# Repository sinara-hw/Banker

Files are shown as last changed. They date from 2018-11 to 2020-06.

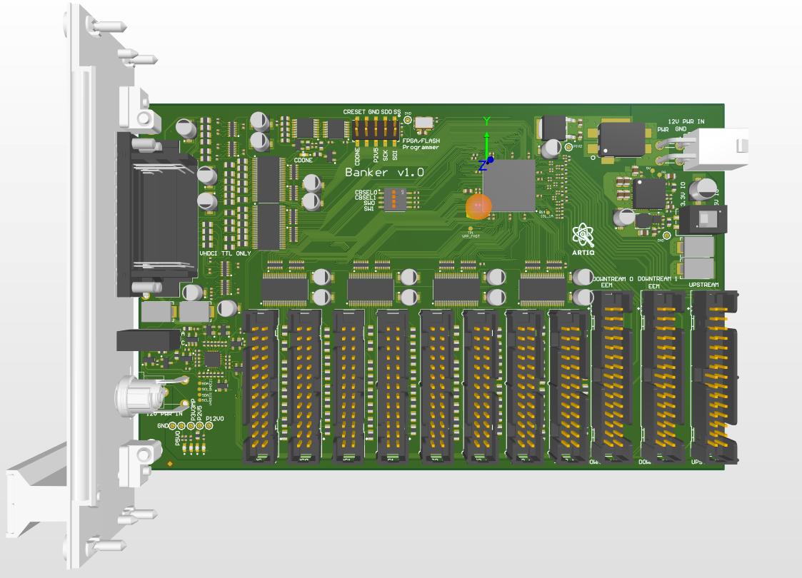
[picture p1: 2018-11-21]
Banker_Top.PNG

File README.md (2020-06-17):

# Banker

EEM with 128 TTL DIOs (64 via local BNC, 64x via VHDCI)

## Design Files

Design files (schematics, PCB layouts, BOMs) can be found at [Banker/Releases](https://github.com/sinara-hw/Banker/releases).

## Wiki

More information can be found on the [wiki](https://github.com/sinara-hw/Banker/wiki).

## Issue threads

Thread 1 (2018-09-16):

schematic review

gkasprow, 2018-09-16:
I did initial [schematics](https://github.com/sinara-hw/Banker/releases/tag/v1.0rc) and component placement.
@jordens @hartytp @dtcallcock @sbourdeauducq please have a look at it.

gkasprow, 2018-09-16:
I did power supply in such way on purpose. When sb plugs it to LVDS port, 5V would be shorted to GND and PTC fuse will get activated. So nothing would be damaged
I used Molex connector (ATX type) on the PCB rear side. I think in next revision of VHDCI carrier and Kasli we should also use them.  It is much more reliable than DC jacks. In case of DC jacks its possible to not lock it. With Molex one it is really hard.
FPGA FLASH can programmed with 10$ programmer, via I2C or via FPGA itself. I added a circuit that allows FPGA to reboot itself.
Additional circuit makes sure that level translators / buffers get activated some time after FPGA configures and reset pulse is released. All IOs have 10k pulldowns.
I2C is protected with TVS
DIP switch is connected to CSBSEL lines that let us choose which binary to boot or can be used as general purpose config input. It is also connected via 10k to FLASH lines that after configuration can be used as GPIO
Front panel LEDs indicate power, Config DONE, I2C FLASH update mode and user defined signal
I2C switch has its own reset circuit
Translators have 22R resistors towards FPGA. It is to limit the current in case of logic level contention.
Downstream ports have 300mA PTCs.
I used 6A 5V DC/DC because it is low cost. And when sb drives 128 channels with 25mA it gives already 3.2A

Shall I add 50Ohm resistors at the drivers output? They take some place and I'm not sure if we need impedance matching.

jordens, 2018-09-17:
Nice!

* Make sure the right pins end up on the GBINs. I'd go for VHDCI0_0, VHDCI1_0, IDC0_0_0, IDC1_0_0, IDC2_0_0, and the 25 MHz clock. On the LVDS bank it's ok.
* I think all the LVDS lines on the three EEM need external termination. Both parallel for input and series for output. Maybe just scrap one downstream EEM if it gets too much.
* The I2C switch reset should be controllable by the FPGA. I see no other way to get out of a hung bus.
* I2C addresses look ok.
* Could we have an easy option to make the TTL level 3.3V (instead of 5V)? Just a couple more resistors/bridges around R367/R368 so that a solder blob will make it 3.3V.
* The drivers have about 10 Ohm output impedance. I'd keep the 30-40 in series. But I see no real need for input parallel termination.
* I don't think the path after IC3 to RSTn to the FPGA is necessary. An internal counter-based delay after configuration should be sufficient. Instead I would drive DRV_OENn from the FPGA (IOL_9B)
* The CFG_RELOAD from the FPGA to CRESET is probably not necessary. There is the SB_WARMBOOT primitive that seems to be able to do that internally. I'd check it though.

* I would put the EEM connectors on the bottom (like Kasli and the others)
* Put the upstream EEM to the right and the downstream ones to the left: "down0, down1, up" from left to right.
* Make sure the bottom (left) VHDCI is VHDCI0 and the top/right VHDCI1.
* Spread out the power and the VHDCI connector as much ass possible on the panel. Without colliding with the handle.
* I'd put the JTAG headers closer to the FPGA.

gkasprow, 2018-09-17:
@jordens ACK All
To simplify routing of power plane I will use 2.5V for all logics.
And will get rid of one downlink EEM. Otherwise I would have to use 6 layers for BGA fanout. I'm not sure if it is worth. It would increase the PCB cost by 30%.
Variable supply for TTL would be generated at the main buck converter, so all IOs would be affected. Is that OK?

jordens, 2018-09-17:
Yes. That's all fine. The alternative would be to have two (3.3/5) domains and split the 128 channels into two power groups. But I don't think that's worth it. People can just get another Banker.

gkasprow, 2018-09-17:
We can indicate 3.3 / 5V operation with front panel LED.

gkasprow, 2018-09-17:
I plan to add  series 33R on each DIO + 50Ohm at the other side of the cable.
In this way when driven from very low impedance, the transmission line would be still source-terminated.
When shorted, the driver will dissipate 5V^2/100R, so two 0.125W resistors would be sufficient.

jordens, 2018-09-17:
Or even 39R.

gkasprow, 2018-09-17:
Yes, I placed 39 Ohms.

gkasprow, 2018-09-19:
@jordens to my surprise, I managed to fanout all signals using mainly2 layers. Just a few signals were routed on third layer reserved for power distribution.
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
Altium pin swapping feature was great help here. Please have a look:
[Banker.PDF](https://github.com/sinara-hw/Banker/files/2397721/Banker.PDF)

dhslichter, 2018-09-19:
How much power dissipation are you going to get if you have 96 channels and each one is driving a 50-ohm terminated load?  The drivers on the schematic will source or sink 32 mA with 5V supply, which means that the logic high will only be 1.6 V across a 50 ohm termination (itself a potential problem).  The dissipation on the board would then be ~100 mW per terminated channel for a logic high, or worst case ~ 10 W.  I think you can't really run a 50 ohm termination at the far end with these lines, would be my point...might have to just plan on the series termination being enough.  You might place a high-current driver on the breakout if you want, for certain channels?

Also, EMI/crosstalk is going to be not great with long cables, and larger currents will make inductive coupling worse....

jordens, 2018-09-19:
I don't think delivering power into 50 ohms on 128 or even only 32 channels is a design goal. I'd just make sure that the power supply trips in a well defined way before anything blows up.

gkasprow, 2018-09-19:
I will add LM75 that will shut down the PSU after exceeding 80 degrees...

dhslichter, 2018-09-19:
All fine.  I just saw comments above talking about terminating loads with 50 ohms at the far end, and I wanted to point out that this is probably not going to work here.  The whole purpose of Banker is to be somewhat time-insensitive digital I/O, though, so I would imagine that they can be made high-impedance inputs.  Series termination at the source will be sufficient for most applications anyway.

jordens, 2018-09-20:
@gkasprow A couple more things after looking again at the [Lattice LVDS AN](https://www.latticesemi.com/-/media/LatticeSemi/Documents/ApplicationNotes/UZ/UsingDifferentialIOLVDSSubLVDSiniCE40Devices.ashx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):

* The positive LVDS (EEMx_y_P) is generally the B pin (IOL_zB), not the A.
* DBIN7 is special and should be EEM0_0_PN as currently but with polarity swapped.
* I would put EEM0_4_P/N on GBIN6 for another SPI bus on EEM0_4-7.
* LVDS outputs need series resistors (mentioned above) as well. We want some outputs. I'd go for EEM0_{2,6}, EEM1_{0,1,3,4,5,7}, EEM2_{0,1,3,4,5,7}. But if there is space, I'd put those series resistor everywhere.

gkasprow, 2018-09-20:
It looks like ICE 40 does not implement LVDS transmitters at all. Only receivers.
I though that these resistive networks are needed for sub-LVDS outputs only.
The image:
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
 states that IOL_1A is positive and IOL_1B is negative

they also say:

 _Connect the positive or true polarity side of the differential pair to the DPxxA input and the negative or complementary side of the pair to the DPxxB input._
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
jordens, 2018-09-25:
* [Banker EDGE2DSUB](https://github.com/sinara-hw/Banker_EDGE_2_DSUB/releases/download/v1.0rc1/Banker_EDGE_2_DSUB.PDF)
* [Banker EDGE2BNC](https://github.com/sinara-hw/Banker_EDGE_2_BNC/releases/download/v1.0rc1/Banker_EDGE_2_BNC.PDF)
* [Banker EDGE2SMA](https://github.com/sinara-hw/Banker_EDGE_2_SMA/releases/download/v1.0rc1/Banker_EDGE_2_SMA.PDF)
* [Banker EDGE2VHDCI](https://github.com/sinara-hw/Banker_VHDCI_2_EDGE/releases/download/v1.0rc1/Banker_VHDCI_2_EDGE.PDF)
* [Banker EDGE2VHDCI Buffered](https://github.com/sinara-hw/Banker_VHDCI_2_EDGE_Buffered/releases/download/v1.0rc1/Banker_VHDCI_2_EDGE_Buffered.PDF)

jordens, 2018-11-26:
@gkasprow I went through the changes in v1.0rc3. Looks all good. Is the N14/TRST_B change without pulldown because there is no space for routing?

gkasprow, 2018-11-26:
hm, I connected N14 to GND.

jordens, 2018-11-26:
Yes. The devboard has a 10k. But gnd is fine afaict.

gkasprow, 2019-01-04:
@jordens the Banker and other CPCIS EEMs will have large cutout to enable passing EEM cables to neighbouring modules.
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

jordens, 2019-01-05:
Argh. I thought we would make them 160 mm. The cutout is a problem as it prevents one board being pulled unless all cables to the right have been removed.

gkasprow, 2019-01-06:
It's hard to fit such big connector and other EEM connectors. On Banker it's doaboe but on Urukul would be extremely hard. The idea with 220mm boards was to make it compatible with existing 160mm EEMs by adding adapter board.
CERN also wants to use 220mm boards.
We can make another thing - leave only tab/tabs with CPCIS connectors. Such tab could be cut when not needed and when somebody wants to fit it in 160mm crate
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

jordens, 2019-01-07:
The connector isn't big. It takes only about a third of the board space of the two EEM IDC connectors.
And with that layout it's still hard to fold the ribbon cables up and over the CPCI PCB nose.
Is the tab approach really better than the adapter board approach? If not then I'd just scrap it and simplify the plan by cutting some options. The slew of options and corner cases currently doesn't convince me. Let's stick with 160mm IDC and 220mm CPCI S.0 with adapter boards for now. Once we have enough momentum, we should then switch the entire collection to CPCI S.0 in one clean cut that also gets rid of the IDC cables. Whether that will be CPCI S.0 160 mm or 220 mm is another question.

gkasprow, 2019-01-07:
Banker involves daisy chain approach that does not comply with backplane anyway. Let's use the adapter idea with following remarks:
- add 2 mouting holes in the corners that will be used to attach such adapter board.
- make sure that position of EEM connectors is same in all EEM boards. In this way in the future we will be able to add rigid version of CPCIS adapter.

We can also move slightly connectors EEM and integrate CPCIs connector with 160mm module, but with such approach we won't have space for IDC cables running to neighbouring Banker boards.
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

gkasprow, 2019-01-07:
the CPCIS adapter board can be implemented as directly plugged mezzanine.
CPCIS specification defines "3.6 Mezzanine Concept"
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
we can do it not only for P6 buf for P1 as well.
With such approach we could get rid of IDC jumpers. The only requirement is same position of EEM connectors on all EEM modules. Since the newest  release we have for Urukul, we can treat it as the reference for other modules.

jordens, 2019-01-07:
* Yes! I am all for fixing the EEM IDC positions on all modules and adding the two mounting holes. That adapter board can be pretty small.
* The daisy-chain approach in Banker will work just fine in two cases: (a) for the short modules (DIO*). Maybe this is a good reason to keep them short. and (b) if Banker is the rightmost on the backplane, then there is plenty of space right of it.
* Making the short modules (DIO*, Grabber, Clocker) CPCI S.0-compatible would mean either using Banker (could be a really good idea) or having a longer adapter.
* For that adapter idea, we need a different, mirrored connector style, right?

gkasprow, 2019-01-07:
It looks like the connectors are symmetrical from mechanical point of view. One need only to make sure the stacking height is 10.8mm.
I plan to order one Schroff chassis, produce adapter board for Banker/Urukul and verify if all fits.

gkasprow, 2019-01-07:
with such placement we are able to use same adapter for Urukul and Banker. In next Urukul revision we will add only mounting holes.
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

Closed 2019-01-10.

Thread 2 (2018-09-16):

VHDCI Breakout

dtcallcock, 2018-09-16:
Greg proposed in [the original Banker RFC](https://github.com/sinara-hw/meta/issues/18#issuecomment-421597904):

**2x 32 channels via VHDCI that can be break-out to 8x D-sub 9 remotely ( on the optical table)**

**If there is interest in other break-out, I can design one.**

And in response to his comments:

> since the VHDCI cable can be already 10m long, does it make sense to make such fanout as 19" form factor? maybe sth smaller that one can put on optical table?

19" is perhaps a bit big for Dsub. However 'on optical table' often means in practice 'in a rack just under/below/beside the optical table'.  Therefore some way of easily adapting the box to rack format is always appreciated, even if it's just a simple bracket like this:

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

For BNC, wont you end up with something about that size anyway as 24 BNCs is already a whole 1U panel (put the other 8 BNCs and the VHCI on the back)?

> How fast are these pulses? is there any standard pinout for Dsub 9 ?

I don't have a specific use case in mind.  I'm just saying that from experience if I build a simple piece of lab electronics that needs 1 or 2 digital connections I will probably use BNCs.  If it needs 3+ I will probably use a D-sub.  I have pretty much every size, gender and mounting configuration, and a bunch of pre-made cables lying around the lab.  They are of large enough pitch I can easily make my own robust cables (inc. ribbon cables) and breakouts are ubiquitus.  I can imagine other people feeling differently though.

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

gkasprow, 2018-09-16:
Such module would need some enclosure with brackets that fit the rack
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

With such approach the PCB itself can be attached to the rack
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

gkasprow, 2018-09-16:
One could use such VHDCI to BNC adapter also to fanout Zotino signals. One can easily get HD68 <-> VHDCI cable and they would fit here.

jordens, 2018-09-17:
For the VHDCI-BNC break-out, I think putting a 2U DIN rail insert ([this](https://www.canford.co.uk/Index/19-inch-rack-DIN-rail-terminal-frames/CANFORD-RACK-MOUNTING-DIN-RAIL-FRAME) or others) into a rack and then using those UM72 ([this](https://www.aliexpress.com/af/um72-pcb.html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) or similar) open PCB modules (which have a lot of break-outs already available) is nicer. It solves the problem of mechanical strength.

gkasprow, 2018-09-17:
@jordens Good idea.
I would extend it slightly.
We can make variety of breakouts using these edge-to-edge connecting systems.
With VHDCI base module and i.e. 8 x BNC + Dsub + terminal block ones we can combine needed outputs in multiple ways.
Here is quick sketch presenting what I mean.
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

jordens, 2018-09-17:
Yes. The central VHDCI could expose its 32 channels in groups of 8 on its right and on its left. That would be four of those 10 pin edge connectors. Then a sub-module grabs the bottom 8 channels and simply forwards the remaining 32-8=24 channels to the next module on the right shifted (mechanically) by 8. Just to a barrel shift by 8 on each sub-module. The resulting stubs are at most the width of a single module. (I hope it's clear what I am trying to say. Otherwise I'll draw some ASCII art.)

jordens, 2018-09-17:
You can arrange this in different ways. If you make each submodule completely point-symmetric (rotation by 180 degrees, by connecting the BNCs to both the bottom left and top right edge connector, like you did in the top row), then you can use them on either side. And you only need to decide whether you do 1,2 left/3,4 right or 1,2,3,4 left/1,2,3,4 right on the VHDCI module. Both will work. And with 1234/1234 you can do more patterns including everything you can do with the 12/34 arrangement.

gkasprow, 2018-09-17:
Yes, the only issue is channel numbering (upside down), which means that additional panel would be needed.

jordens, 2018-09-17:
No. The entire thing is 4-periodic. The "bottom" group-of-8-channels on a string of 5 modules are `|41|-|12|-|23|-|34|-|41|` Have the VHDCI module be the left one or the right one (`|41|` here) and the submodules will always nicely be numbered from left to right. And within each group there is also no issue.

gkasprow, 2018-09-17:
I meant that if we print channel numbering, then rotate the module, the letters and digits would be upside down :)

jordens, 2018-09-17:
Yes. Only the electrical interface needs to be rotationally symmetric, not the panel.

gkasprow, 2018-09-17:
I'd like to avoid panels. The modules channels can be printed on the PCB. So we would have to live with  stubs anyway or use twice more board-to-board connectors like in the second conception. Of course some connectors may be not populated. In first conception with the central VHDCI module we would need just 8 connectors (and short stubs). In second conception with all slots populated we need 16 connectors. Their number can be however reduced to 10 because 6 are not active.

jordens, 2018-09-26:
* [Banker EDGE2DSUB](https://github.com/sinara-hw/Banker_EDGE_2_DSUB/releases/download/v1.0rc1/Banker_EDGE_2_DSUB.PDF)
* [Banker EDGE2BNC](https://github.com/sinara-hw/Banker_EDGE_2_BNC/releases/download/v1.0rc1/Banker_EDGE_2_BNC.PDF)
* [Banker EDGE2SMA](https://github.com/sinara-hw/Banker_EDGE_2_SMA/releases/download/v1.0rc1/Banker_EDGE_2_SMA.PDF)
* [Banker EDGE2VHDCI](https://github.com/sinara-hw/Banker_VHDCI_2_EDGE/releases/download/v1.0rc1/Banker_VHDCI_2_EDGE.PDF)
* [Banker EDGE2VHDCI Buffered](https://github.com/sinara-hw/Banker_VHDCI_2_EDGE_Buffered/releases/download/v1.0rc1/Banker_VHDCI_2_EDGE_Buffered.PDF)

Closed 2018-09-26.

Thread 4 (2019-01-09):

panel

gkasprow, 2019-01-09:

jordens, 2019-01-10:
Good.
IIRC there was a confusion about the VHDCI connector naming (top/bottom vs 1/0) way back with VHDCICarrier. Is that resolved here?

jordens, 2019-01-10:
It's a bit hard to tell from that image: the cable shield and the retaining hooks/screws should easily fit through the panel.

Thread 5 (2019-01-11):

[I2C switch] move TEMP to port 0 (with EEPROM) and put EEM2 on port 5

jordens, 2019-01-11:
That way either the FPGA or EEM2 can be the master (as it is now) and the other one can always be mapped on one of the slave ports (FPGA on port 1 and EEM2 on port 5).
Currently, if the FPGA is the master, EEM2 is either always connected or always disconnected to the I2C tree.
This is minor and can go into v1.1.

gkasprow, 2019-01-11:
done

Closed 2019-01-11.

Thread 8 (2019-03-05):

Banker tests

gkasprow, 2019-03-05:
The banker arrived!
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

gkasprow, 2019-03-06:
power supply works fine after R166 fix. 3.3/5V switching works as well.

jordens, 2019-03-06:
Nice! If you can write a bitstream to the flash and toggle an output that's fine to send.

hartytp, 2019-03-06:
Nice! Remind me when Sayma AMC/RTM will be ready for review ;)

gkasprow, 2019-03-06:
@jordens I wrote a simple LED blink code but could not find a Lattice programmer. I had 2 of them but they disappeared.
Fortunately, I found a devkit and tomorrow will connect it and check if FPGA configures and FPGA blinks. ThenI will send it to you.  In terms of Sayma I will close issues and make a new release tomorrow.

gkasprow, 2019-03-07:
it's ready now.

gkasprow, 2019-03-07:
the LED blinks on Banker.

gkasprow, 2019-03-07:
the SPI programming andFPGa booting also works. One need to exchange SDI with SDO lines to program FLASH. Use such settings with Diamond programmer:
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

gkasprow, 2019-03-07:
the FPGA project that blinks LED is here:
[Humpback.zip](https://github.com/sinara-hw/Banker/files/2941697/Humpback.zip)

gkasprow, 2019-03-07:
I ised low cost ICE40 stick devkit as a programmer. Just remove a few 0R resistors nad connect the header.  It's essentially FTDI FT2232HL chip

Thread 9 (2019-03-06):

Banker Errata

gkasprow, 2019-03-06:
- [ ] pull DC/DC enable line to 12V

jordens, 2019-03-13:
* [ ] SW2 labels (5V/3V3) are swapped. It's 5V if the switch points to the front.

airwoodix, 2019-05-26:
- [ ] EEM signals have reversed polarity (see sinara-hw/Humpback#9)

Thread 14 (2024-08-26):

Swapped SW2 labels

kaolpr, 2024-08-26:
- [ ] Labels on SW2 are swapped, `3.3V IO` position corresponds to 5V, and `5V IO` to 3.3V.
- [ ] Net name `P5V0` is misleading, it should be changed in schematics.
- [ ] Test point should be renamed accordingly.

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

jordens, 2024-08-26:
https://github.com/sinara-hw/Banker/issues/9#issuecomment-472502021

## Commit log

2018-09-16 v1.0 schematics ready for review
    [Banker.PrjPCB, Banker.schdoc, FPGA.SchDoc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]
2018-11-21 img update
    [Banker.schdoc, FPGA.SchDoc, FPGA_Config.SchDoc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]
2019-01-06 added CPCIS support
    [Banker.PrjPCB, Banker.schdoc, CPCISerial_connector.SchDoc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]
2019-01-11 fixed #5
    [Banker.PrjPCB, FPGA.SchDoc, FPGA_LVDS.SchDoc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]
